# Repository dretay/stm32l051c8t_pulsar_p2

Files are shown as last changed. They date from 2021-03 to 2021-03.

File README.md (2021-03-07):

# Pulsar P2 

> New PCB, PCB Carrier, and firmware for the restoration of a the world's first digital watch.

In 1972 Hamilton released the Pulsar P2, the world's first commercially available digital watch. This watch featured a distinctive "dot" led display and did nothing more than display the time. As technology moved on LED-based watches fell out of favor due to their high energy usage and were replaced by much more efficient LCD-based watches. As a result most of these early watches were thrown into drawers and left for decades unused with their old batteries still installed. Over time the batteries would leak gas and corrosive acids that destroyed the watch's PCB and rendered it non-functional. This project documents my restoration of a non-functional Pulsar P2 by harvesting the original LED panel and inserting it into a modern redesigned PCB.  

### Main Features

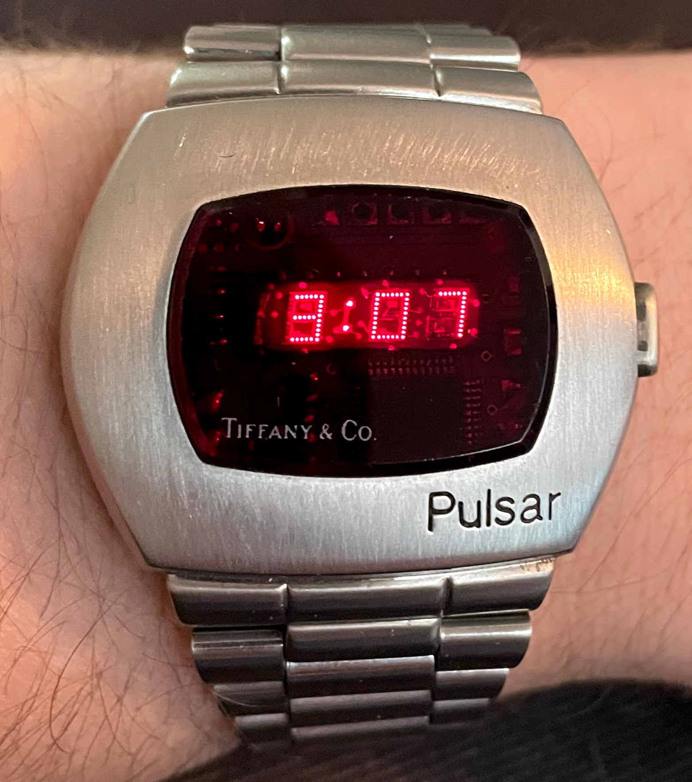
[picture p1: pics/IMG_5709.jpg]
- Very low idle current consumption 
  - The watch sleeps at 5uA of power consumption, with most of that (4uA) coming from the crystal oscillator. 
  - Highly efficient LED driving - the segments are charlieplex'd and there is a built-in ambient light sensor to control the brightness. When displaying time the consumption is between 20mA and 50mA. 
  - Worst-case battery life of 4 hours (display always on) and best-case life of 4.5 years (display never turned on)

### Build Instructions

#### PCB Design

The PCB was designed in Altium CircuitMaker. You can download the project [here](https://circuitmaker.com/Projects/Details/Andrew-Tayman/Pulsar-P2-Board) if you want to edit it yourself or you can grab the Gerber and Drill files that were uploaded [here](https://github.com/dretay/stm32l051c8t_pulsar_p2/raw/master/resources/Pulsar%20P2%20Layout.zip). If you want you can also just put in an OshPark order yourself [here](https://oshpark.com/shared_projects/0NyVLPPb).

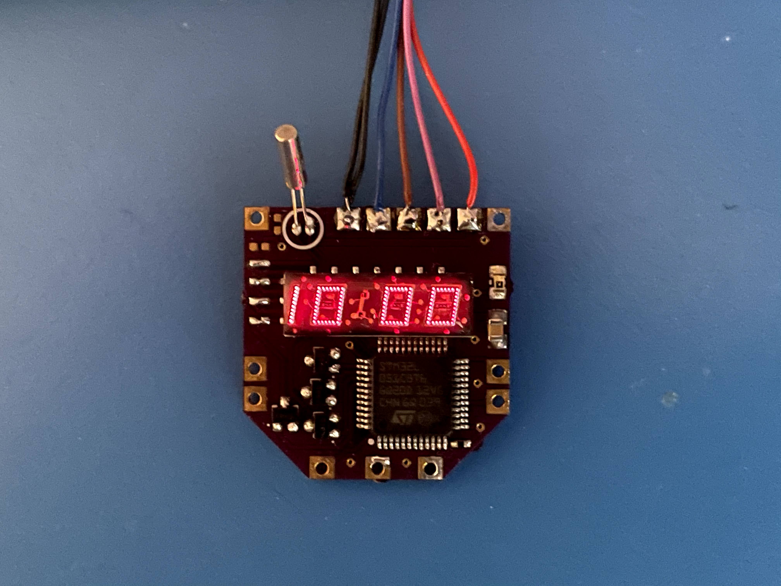
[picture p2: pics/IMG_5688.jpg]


*I'll do my best to keep the static resources up-to-date, but for best results you should pull the project directly out of CircuitMaker. **Note**: I ended up ditching the crystal and using an oscillator for the RTC... a newer design needs to be spun that incorporates that.* 

#### PCB Carrier

One idea I had but haven't had the time to fully execute was to replace the old Pulsar PCB carrier with a newer CNC milled version. The original watch used an obsolete #355 watch battery. These are no longer manufactured, and you must now use #357 batteries with spacers. These spacers can cause issues if not precisely made due to them binding to the battery or putting too much pressure on the watch case and causing incorrect seals. Furthermore #357 batteries have a smaller capacity than the original #357 (due to their smaller size) and thus must be changed more frequently. I modeled out the original PCB carrier as a 3D rendering, which should allow me to change the battery to either support a #355 natively or to swap it out entirely for a higher-capacity (and rechargeable) battery like  a CR2032. You can download the STL files for this carrier [here](https://github.com/dretay/stm32l051c8t_pulsar_p2/raw/master/resources/pulsar_p2_carrier.stl) or get the raw design itself by going [here](https://a360.co/2O2gdrLSetting). 

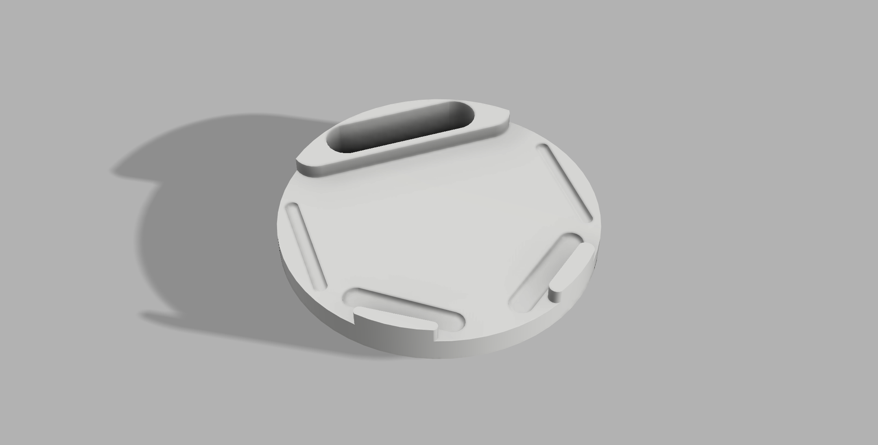
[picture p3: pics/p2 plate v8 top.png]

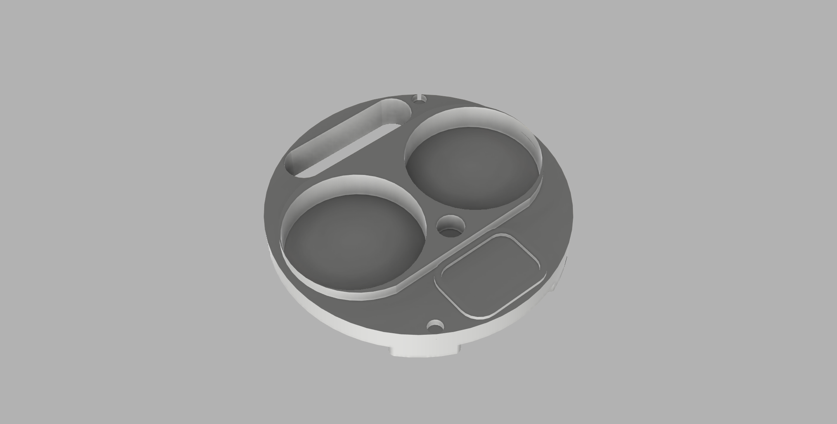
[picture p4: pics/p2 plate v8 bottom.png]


#### Source code 

This project makes use of a few reusable libraries I wrote to help handle some common needs: 

- The [Timer](https://github.com/dretay/stm32_timer) library helps implement a simple software-based scheduling / timer solution without needing to incorporate a heavy RTOS library. 
- The [PushButton](https://github.com/dretay/stm32_pushbutton) library is a software-based button debouncing solution that helps organize button actions and provides higher-level abstractions like "long push" and "double push."

Beyond these libraries the project itself was built in STM32CubeIDE. The software coordinates actions through logic defined in [Application.c](https://github.com/dretay/stm32l051c8t_pulsar_p2/blob/master/Core/Src/Application.c).  

#### Energy Usage

A major challenge with this project was getting energy usage as low as possible and characterizing the watch's behavior under different levels of battery charge. I used a Keithley 2450 SourceMeter to build a discharge model for the two LR44 batteries I was using to power the watch. I fixed the batteries together with a clamp with a small strip of aluminum on each side. I then used some kelvin clips to connect the batteries to the sourcemeter so I could characterize them.

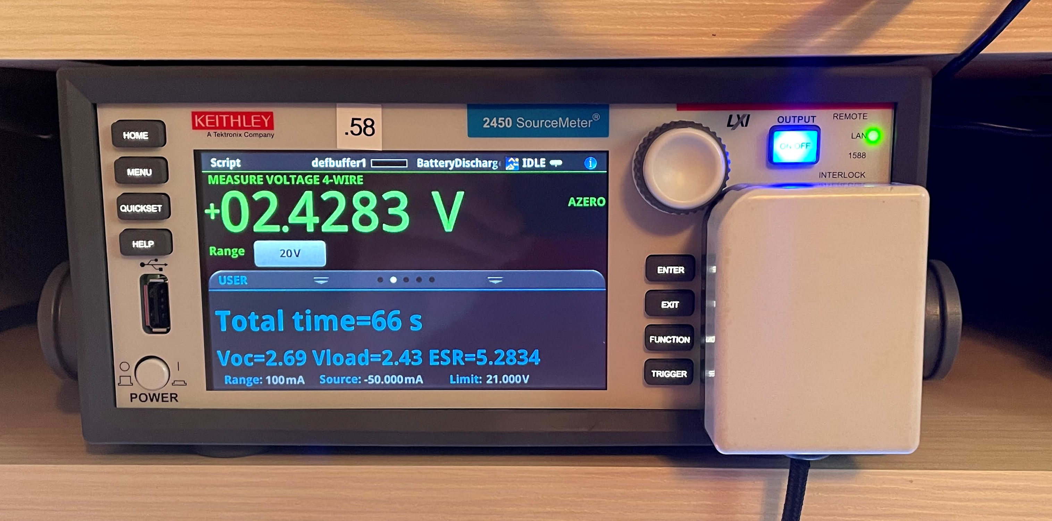
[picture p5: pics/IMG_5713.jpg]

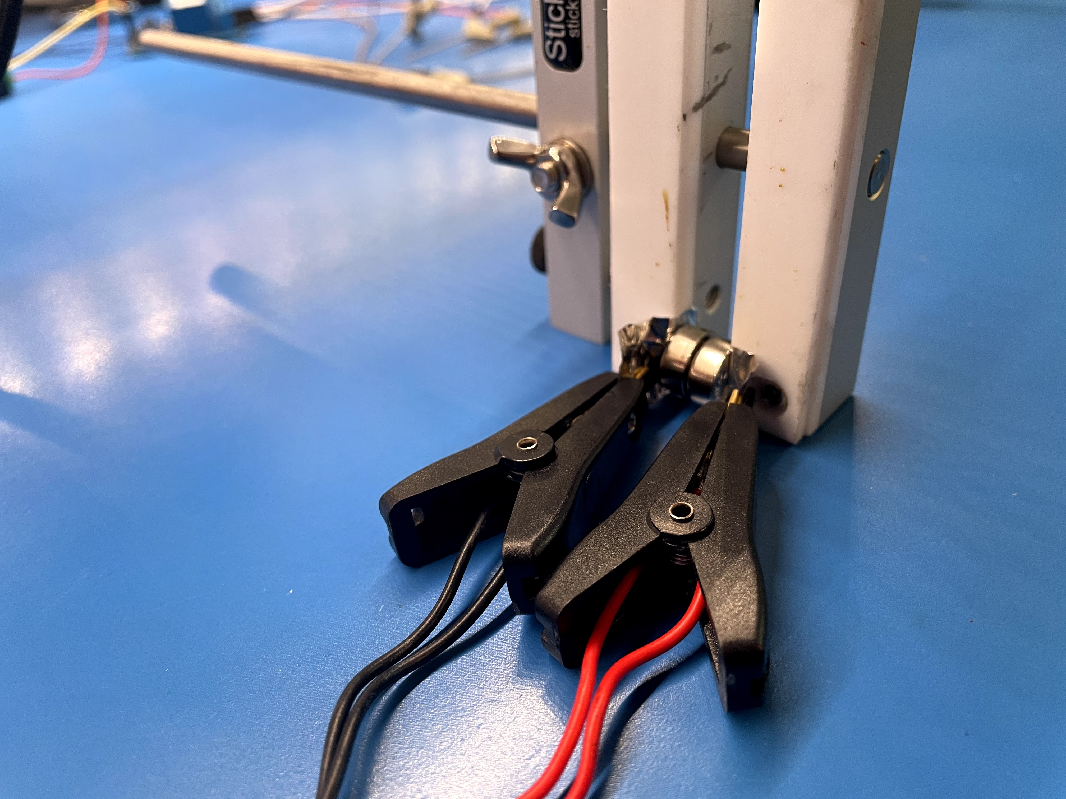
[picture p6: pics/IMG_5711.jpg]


I was then able to load the resulting model into a Keithley 2281s Battery Simulator and ensure proper behavior a lower battery charge levels.
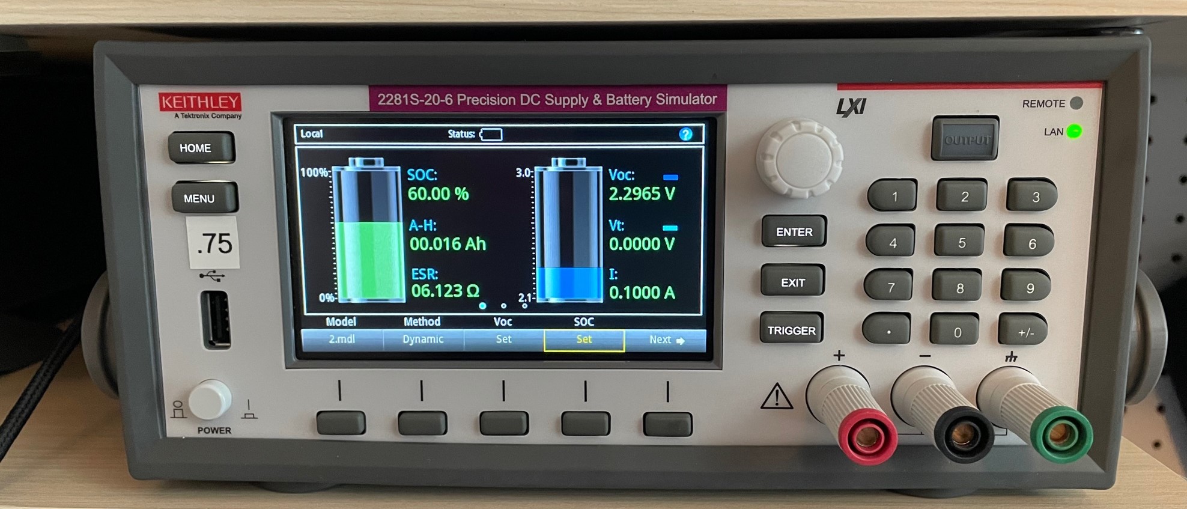
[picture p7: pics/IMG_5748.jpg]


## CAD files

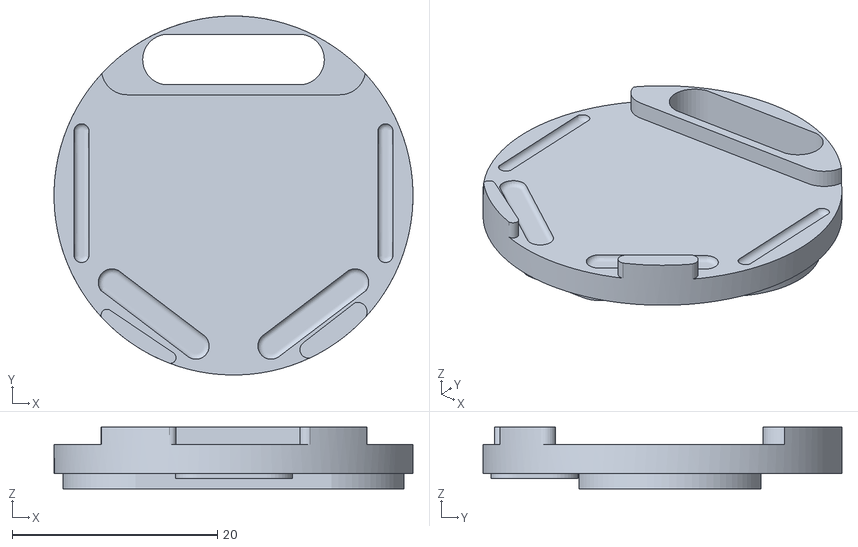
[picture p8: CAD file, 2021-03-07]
resources/pulsar_p2_carrier.stl
35.0 x 35.0 x 6.00

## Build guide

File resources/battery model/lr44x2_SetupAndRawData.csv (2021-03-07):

TEST_PARAM.comment: | lr44 2x
SourceMeter Model: | 2450
SourceMeter S/N: | 04036355
SourceMeter Firmware: | 1.7.5b
TEST_PARAM.terminals: | FRONT TERMINALS
TEST_PARAM.initial_voc: | 3.0592660904
TEST_PARAM.vcutoff: | 1.65
TEST_PARAM.discharge_type: | CONSTANT
TEST_PARAM.discharge_current: | 0.05
TEST_PARAM.max_discharge_current: | 0.05
TEST_PARAM.measure_interval: | 2
TEST_PARAM.discharge_start_time: | 02/26/21 14:04:37
TEST_PARAM.discharge_stop_time: | 02/26/21 14:35:54
BATT_MODEL_RAW: | Index | Timestamp | Voc | Vload | ESR
BATT_MODEL_RAW: | 1 | 0.03483104 | 3.0448379517 | 2.7652053833 | 5.5926513672
BATT_MODEL_RAW: | 2 | 2.03546566 | 2.9426994324 | 2.6627998352 | 5.5979919434
BATT_MODEL_RAW: | 3 | 4.03572704 | 2.904296875 | 2.6254768372 | 5.5764007568
BATT_MODEL_RAW: | 4 | 6.03655048 | 2.879108429 | 2.601146698 | 5.5592346191
BATT_MODEL_RAW: | 5 | 8.03752154 | 2.8601493835 | 2.5830345154 | 5.5422973633
BATT_MODEL_RAW: | 6 | 10.03837794 | 2.8448104858 | 2.5685195923 | 5.5258178711
BATT_MODEL_RAW: | 7 | 12.03943766 | 2.8318901062 | 2.5564041138 | 5.5097198486
BATT_MODEL_RAW: | 8 | 14.04036922 | 2.8206672668 | 2.5459518433 | 5.4943084717
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

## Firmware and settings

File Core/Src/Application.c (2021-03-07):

#include "Application.h"

static int STOP_TIMER_HANDLE = -1;
static int MINUTE_INCREMENT_HANDLE = -1;
static int HOUR_INCREMENT_HANDLE = -1;
static u32 WAKE_MSECONDS = 1000;

extern void EXT_SystemClock_Config(void);

static void reset_stop_timer();

//static bool wake = false;

static void on_wake(void)
{
    //	wake = false;
    //reconfigure clock
    EXT_SystemClock_Config();

    //fetch time
    Clock.init();

    //start adc
    Adc.start();

    //start stop timer back up
    reset_stop_timer();

    //	HAL_NVIC_EnableIRQ(EXTI0_1_IRQn);
    //	HAL_NVIC_EnableIRQ(EXTI4_15_IRQn);
}
static void on_stop(void)
{
    app_log_debug("preparing for standby... ");

    Led.off();
    Adc.stop();
    app_log_debug("entering standby");
    HAL_PWR_EnterSTOPMode(PWR_LOWPOWERREGULATOR_ON, PWR_STOPENTRY_WFI);
    on_wake();
}
static void stop_stop_timer()
{
    Timer.cancel(STOP_TIMER_HANDLE);
    STOP_TIMER_HANDLE = -1;
}
static void reset_stop_timer()
{
    app_log_debug("resetting shutdown timer... ");
    if (!Timer.reset(STOP_TIMER_HANDLE)) {
        app_log_append("creating shutdown timer");
        STOP_TIMER_HANDLE = Timer.in(WAKE_MSECONDS, on_stop);
    }
}

void hour_increment(void)
{
    if (HOUR_INCREMENT_HANDLE == -1) {
        HOUR_INCREMENT_HANDLE = Timer.every(500, hour_increment);
    }
    Clock.increment_hour(1);
    stop_stop_timer();
}
void hour_increment_stop(void)
{
    if (Timer.cancel(HOUR_INCREMENT_HANDLE)) {
        HOUR_INCREMENT_HANDLE = -1;
        reset_stop_timer();
        app_log_debug("stopped hour increment timer");
    } else {
        app_log_error("failed to stop hour increment timer");
    }
}

void minute_increment(void)
{
    if (MINUTE_INCREMENT_HANDLE == -1) {
        MINUTE_INCREMENT_HANDLE = Timer.every(500, minute_increment);
    }
    Clock.increment_minute(1);
    stop_stop_timer();
}
void minute_increment_fast(void)
{
    if (!Timer.cancel(MINUTE_INCREMENT_HANDLE)) {
        app_log_debug("failed to stop slow minute increment");
    }
    MINUTE_INCREMENT_HANDLE = Timer.every(500, minute_increment_fast);
    Clock.increment_minute(1);
}
void minute_increment_stop(void)
{
    if (Timer.cancel(MINUTE_INCREMENT_HANDLE)) {
        MINUTE_INCREMENT_HANDLE = -1;
        reset_stop_timer();
        app_log_debug("stopped minute increment timer");
    } else {
        app_log_error("failed to stop minute increment timer");
    }
}
void read_short_press(void)
{
    reset_stop_timer();
}

static void init(void)
{
    app_log_debug("application starting");

    PushButton.init();
    PushButton.register_button(
        (struct button_config) {
            .button_down_short = &hour_increment,
            .button_up = &hour_increment_stop,
            .gpio_pin = HR_SET_BTN_Pin,
            .gpio_port = HR_SET_BTN_GPIO_Port });
    PushButton.register_button(
        (struct button_config) {
            .button_down_short = &minute_increment,
            .button_up = &minute_increment_stop,
            .gpio_pin = MIN_SET_BTN_Pin,
            .gpio_port = MIN_SET_BTN_GPIO_Port });
    PushButton.register_button(
        (struct button_config) {
            .button_down_short = &read_short_press,
            .gpio_pin = READ_BTN_Pin,
            .gpio_port = READ_BTN_GPIO_Port });
    Clock.init();
    Timer.init();
    Adc.init();
    Led.init();
    Timer.every(50, PushButton.loop);
    //		Timer.every(1000, Clock.loop);
    Timer.every(200, Adc.poll);
    //	STOP_TIMER_HANDLE = Timer.in(WAKE_MSECONDS, on_stop);
    reset_stop_timer();
    //	HAL_PWREx_EnableLowPowerRunMode(); //set regulator to low power mode
    //	HAL_PWREx_EnableUltraLowPower(); //disable internal voltage reference
    //	HAL_PWR_EnterSTANDBYMode();
    //	HAL_PWREx_EnableFastWakeUp(); //controls whether to wait for internal voltage startup time
    //	__HAL_RCC_WAKEUPSTOP_CLK_CONFIG(RCC_STOP_WAKEUPCLOCK_MSI);
    //	Clock.increment_hour();
    app_log_debug("application started");
}
extern RTC_HandleTypeDef hrtc;
static void loop(void)
{
    Timer.tick();
    Led.draw();
}
void HAL_GPIO_EXTI_Callback(uint16_t GPIO_Pin)
{
    app_log_trace("external interrupt triggered!");
    if (GPIO_Pin == HR_SET_BTN_Pin) {
        PushButton.signal_state_change(GPIO_Pin, false);
    }
    if (GPIO_Pin == MIN_SET_BTN_Pin) {
        PushButton.signal_state_change(GPIO_Pin, false);
    }
    if (GPIO_Pin == READ_BTN_Pin) {
        PushButton.signal_state_change(GPIO_Pin, false);
    }
}

const struct application Application = {
    .init = init,
    .loop = loop,

};

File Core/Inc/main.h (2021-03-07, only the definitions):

#define HR_SET_BTN_Pin GPIO_PIN_13
#define HR_SET_BTN_GPIO_Port GPIOC
#define MIN_SET_BTN_Pin GPIO_PIN_0
#define MIN_SET_BTN_GPIO_Port GPIOA
#define LIGHT_SENSE_Pin GPIO_PIN_2
#define LIGHT_SENSE_GPIO_Port GPIOA
#define READ_BTN_Pin GPIO_PIN_7
#define READ_BTN_GPIO_Port GPIOA
#define LCD_A_Pin GPIO_PIN_14
#define LCD_A_GPIO_Port GPIOB
#define LCD_B_Pin GPIO_PIN_15
#define LCD_B_GPIO_Port GPIOB
#define LCD_D_Pin GPIO_PIN_8
#define LCD_D_GPIO_Port GPIOA
#define LCD_C_Pin GPIO_PIN_9
#define LCD_C_GPIO_Port GPIOA
#define LCD_E_Pin GPIO_PIN_10
#define LCD_E_GPIO_Port GPIOA
#define LCD_F_Pin GPIO_PIN_11
#define LCD_F_GPIO_Port GPIOA
#define LCD_G_Pin GPIO_PIN_12
#define LCD_G_GPIO_Port GPIOA
#define LCD_S4_Pin GPIO_PIN_15
#define LCD_S4_GPIO_Port GPIOA
#define LCD_S3_Pin GPIO_PIN_3
#define LCD_S3_GPIO_Port GPIOB
#define LCD_S2_Pin GPIO_PIN_4
#define LCD_S2_GPIO_Port GPIOB
#define LCD_S1_Pin GPIO_PIN_5
#define LCD_S1_GPIO_Port GPIOB

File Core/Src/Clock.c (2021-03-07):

#include "Clock.h"

#if defined STM32L0xx_HAL_RTC_H
extern RTC_HandleTypeDef hrtc;
#endif

static s32 CURR_MINUTES, CURR_HOURS;
static bool TIME_MODIFIED = false;

static void commit_time()
{
    RTC_TimeTypeDef sTime = { 0 };
    sTime.Hours = CURR_HOURS;
    sTime.Minutes = CURR_MINUTES;
    sTime.Seconds = 0;
    sTime.TimeFormat = RTC_HOURFORMAT12_AM;
    sTime.DayLightSaving = RTC_DAYLIGHTSAVING_NONE;
    sTime.StoreOperation = RTC_STOREOPERATION_RESET;
    if (HAL_RTC_SetTime(&hrtc, &sTime, RTC_FORMAT_BIN) != HAL_OK) {
        app_log_error("error setting time");
    }
}
static void increment_hour(u32 hours)
{
    app_log_debug("incrementing hours");
    CURR_HOURS += hours;
    if (CURR_HOURS > 12) {
        CURR_HOURS = 1;
    }
    commit_time();
}
static void increment_minute(u32 minutes)
{
    app_log_debug("incrementing minutes");
    CURR_MINUTES += minutes;
    if (CURR_MINUTES > 60) {
        CURR_MINUTES = 0;
        increment_hour(1);
    }
    commit_time();
}
static void init(void)
{
    RTC_DateTypeDef sdatestructureget;
    RTC_TimeTypeDef stimestructure;

    /* Get the RTC current Time */
    HAL_RTC_GetTime(&hrtc, &stimestructure, RTC_FORMAT_BIN);

    //even though we don't use it, have to fetch it to unlock the register
    HAL_RTC_GetDate(&hrtc, &sdatestructureget, RTC_FORMAT_BIN);

    CURR_HOURS = stimestructure.Hours;
    CURR_MINUTES = stimestructure.Minutes;
    app_log_debug("rtc init: %d:%d", CURR_HOURS, CURR_MINUTES);
}
static void loop()
{
    s32 hours = Clock.get_hours();
    s32 minutes = Clock.get_minutes();
    u8 hours_top = (hours / 10) % 10;
    u8 hours_bottom = hours % 10;
    u8 minutes_top = (minutes / 10) % 10;
    u8 minutes_bottom = minutes % 10;

    app_log_info("%d%d:%d%d", hours_top, hours_bottom, minutes_top, minutes_bottom);
}
static int get_minutes(void)
{
    return CURR_MINUTES;
}
static int get_hours(void)
{
    return CURR_HOURS;
}
const struct clock Clock = {
    .init = init,
    .loop = loop,
    .increment_hour = increment_hour,
    .increment_minute = increment_minute,
    .commit_time = commit_time,
    .get_minutes = get_minutes,
    .get_hours = get_hours
};

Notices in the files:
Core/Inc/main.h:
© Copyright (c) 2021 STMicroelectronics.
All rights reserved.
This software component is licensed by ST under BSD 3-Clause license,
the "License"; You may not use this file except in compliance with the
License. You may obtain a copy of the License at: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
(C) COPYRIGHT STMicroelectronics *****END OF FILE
